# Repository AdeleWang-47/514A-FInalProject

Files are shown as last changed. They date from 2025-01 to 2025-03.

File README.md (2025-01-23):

# 514A-FInalProject
## Section 1
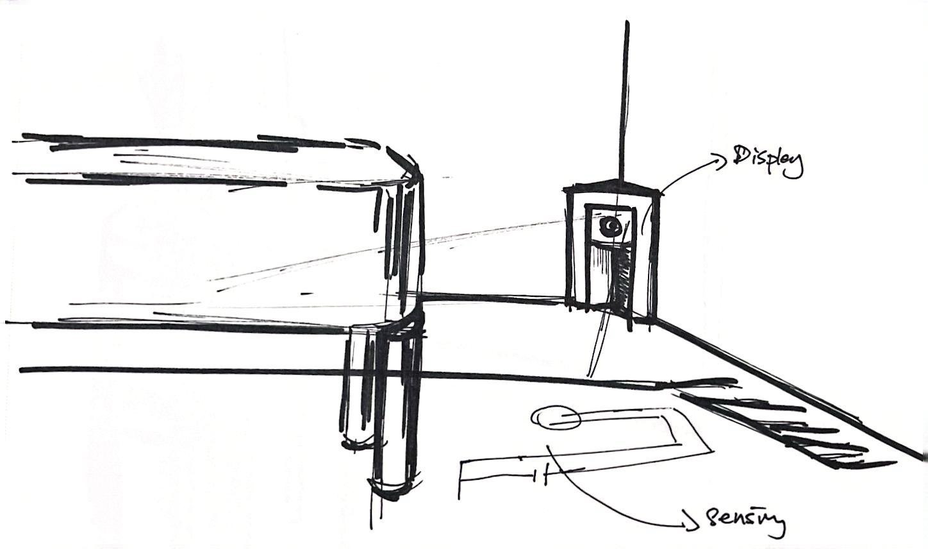
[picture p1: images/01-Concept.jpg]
Concept

A system to provide safe, low-brightness lighting when users get out of bed at night. 
One sensing device shaped like a carpet and one displaying device can be place at the corner of the room to light the path for user.

## Section 2
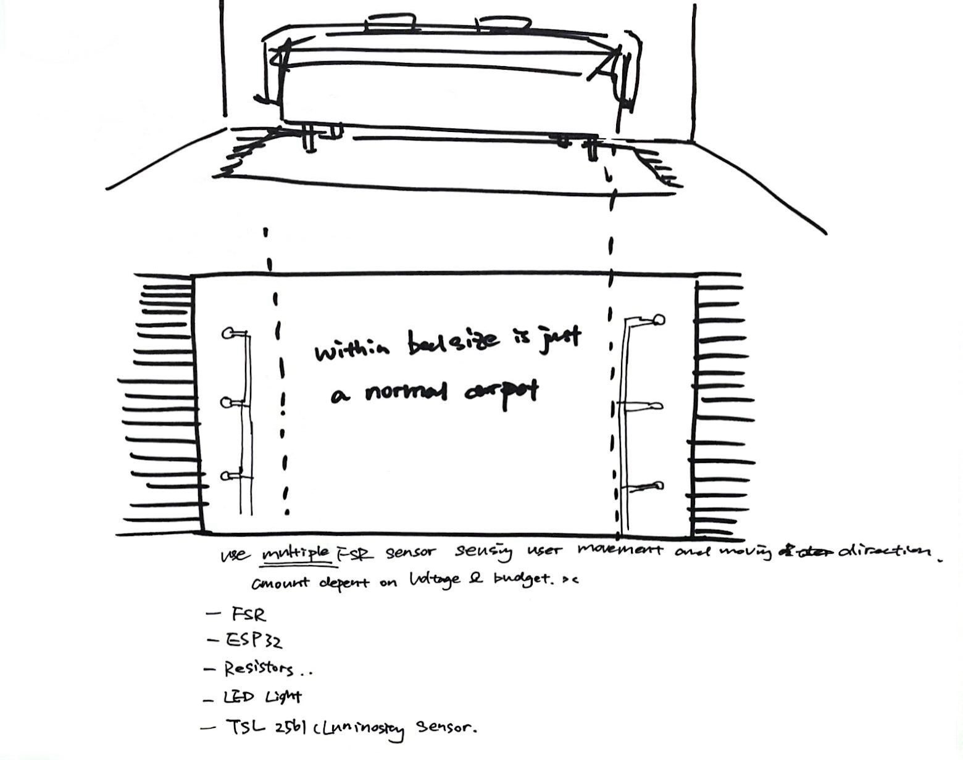
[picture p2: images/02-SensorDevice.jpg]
Sensor

## Section 3
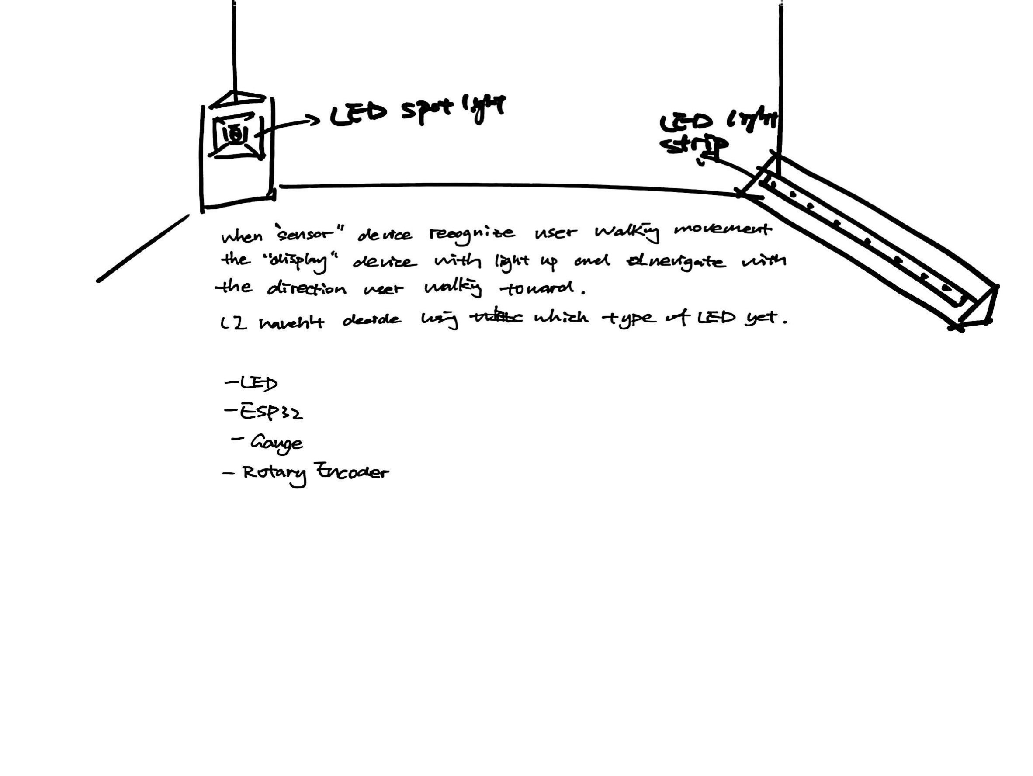
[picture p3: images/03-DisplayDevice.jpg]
Display

## Section 4
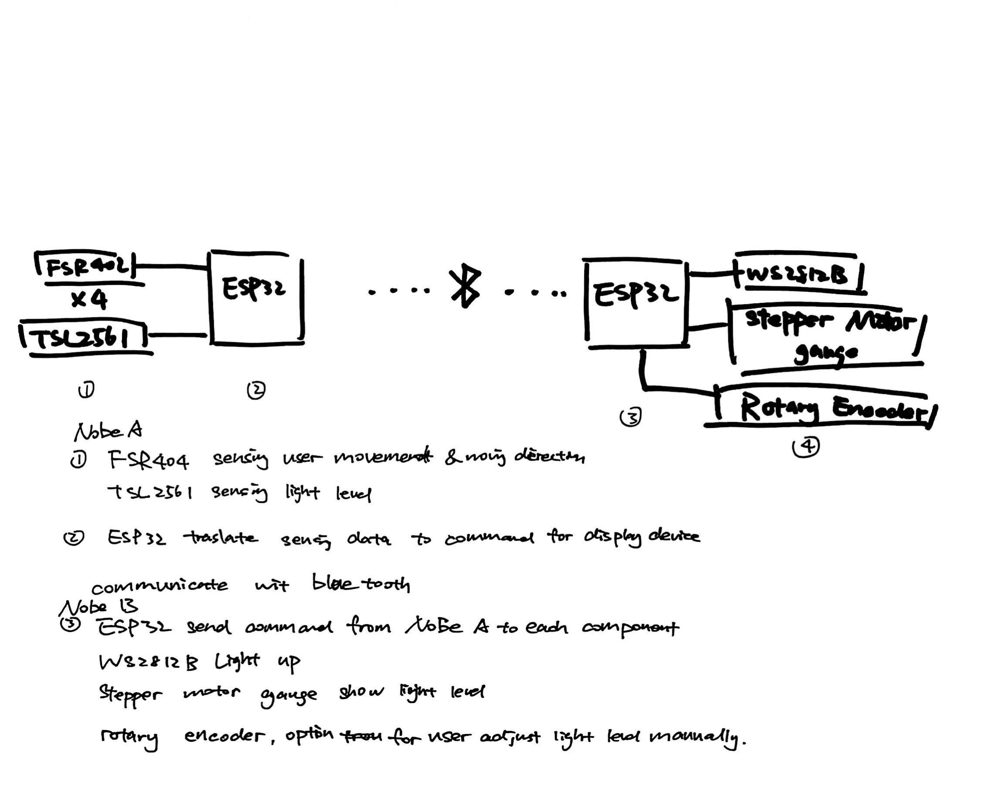
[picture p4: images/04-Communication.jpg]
Communication


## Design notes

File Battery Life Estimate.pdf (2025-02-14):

Battery Life Estimate
TECHIN 514
Adele Wang
13.02.2025

Power Consumption of Each Node

Node A (Sensing Node)

Component | Voltage (V) | Current (mA) | Power (mW)
ESP32-C3 | 3.3V | ~100mA | 330mW
FSR Sensors (x4) | 3.3V | ~4mA each | 13.2mW
Light Sensor (TSL2591) | 3.3V | ~0.4mA | 1.32mW
Total Power for Node A | - | - | ~345mW

Node B (Display & Output Node)

Component | Voltage (V) | Current (mA) | Power (mW)
ESP32-C3 | 3.3V | ~100mA | 330mW
Stepper Motor (X27) | 3.3V | ~150mA | ~500mW
WS2812B LED Strip (1m, 60 LEDs) | 5V (separate power) | ~1200mA max | 6000mW max
Total Power for Node B (excluding LEDs) | - | - | ~830mW

System Usage Model

- Estimate 4 times per night
- Each usage lasts 5 minutes
- Total daily usage: 20 minutes

Battery Selection & Capacity Calculation

Nodes A & B (ESP32 + Sensors + Stepper) - Powered by 18650 Battery

Daily Energy Consumption (20 min/day)

Node | Power (mW) | Daily Usage (min) | Daily Energy (mWh)
Node A (ESP32 + sensors) | ~345mW | 20 | 115mWh
Node B (ESP32 + stepper, excluding LEDs) | ~830mW | 20 | 277mWh
Total Energy (both nodes) | - | - | 392mWh/day

Battery Energy Available (18650 Li-ion 3.7V, 2500mAh)
2500mAh×3.7V=9250mWh

After LDO conversion (~85% efficiency):

9250mWh×0.85=7862.5mWh

Estimated Battery Life

For a 2500mAh 18650 battery:

Node | Battery Life (2500mAh 18650)
Node A (ESP32 + sensors) | ~68.3 days
Node B (ESP32 + stepper) | ~28.4 days

For a 3500mAh 18650 battery:

Node | Battery Life (3500mAh 18650)
Node A (ESP32 + sensors) | ~95.7 days
Node B (ESP32 + stepper) | ~39.8 days

WS2812B LED Strip - Powered by USB Power Bank

- Max Power Consumption: 6000mW (full brightness)
- Estimated Duty Cycle (~30%) → 1800mW average
- Daily Usage: 20 min

1800mW×2060=600mWh/day

For a 10,000mAh USB power bank (5V):

10,000mAh×5V=50,000mWh

Estimated LED Strip Runtime
50,000mWh600mWh≈83 days

Final Battery Life Estimates

System | Power Source | Estimated Runtime Before Recharge
Node A (ESP32 + sensors) | 18650 (3.7V, 2500mAh) | ~68.3 days
Node B (ESP32 + stepper motor) | 18650 (3.7V, 2500mAh) | ~28.4 days
LED Strip (WS2812B, 1m) | USB Power Bank (10,000mAh, 5V) | ~83 days

Reflection

How did you determine your "days of use" metric?

The "days of use" metric is calculated based on the estimated power consumption of each component, the battery capacity, and the expected daily usage.

- Power consumption for each node is determined by summing up the power of all components.
- Daily energy consumption is computed using the estimated duty cycle (4 activations per day, 5 minutes each, totaling 20 minutes/day).
- Battery life is estimated by dividing the available energy of the battery (considering efficiency loss) by the daily energy consumption.

For the LEDs, I estimate their average power consumption at 30% brightness rather than maximum usage to reflect real-world conditions.

What do you think is the optimum size for the battery in your device?

- For Node A (ESP32 + sensors): A 2500mAh 18650 battery can last ~68.3 days, while a 3500mAh battery extends this to ~95.7 days. Since the sensing node consumes relatively low power, a 2500mAh battery is sufficient for at least 2 months of operation.
- For Node B (ESP32 + stepper motor): A 2500mAh battery provides ~28.4 days of operation, which may require recharging monthly. Upgrading to a 3500mAh battery extends this to ~39.8 days, making it a more practical choice.
- For WS2812B LED Strip: A 10,000mAh USB power bank offers ~83 days of operation. A 5,000mAh power bank would still last ~41 days, making it a good tradeoff between cost and battery life.

Thus, my battery setup would be:
- Node A: 2500mAh (or 3500mAh for longer duration)
- Node B: 3500mAh (to reduce frequent recharges)
- LEDs: 5,000mAh or 10,000mAh USB power bank

What hardware/software/cost/effort tradeoffs could you make to improve the user experience?

Tradeoff Type | Improvement | Pros | Cons
Hardware - LED Power | Lower LED brightness (adaptive control) | Extends USB power bank life | Might reduce visibility

Software - Sleep Mode | Enable deep sleep for ESP32 when idle | Reduces power consumption significantly | Requires additional wake-up logic
Software - Sensor Optimization | Lower FSR & light sensor polling frequency | Less frequent wake-ups save power | Might slightly delay response time

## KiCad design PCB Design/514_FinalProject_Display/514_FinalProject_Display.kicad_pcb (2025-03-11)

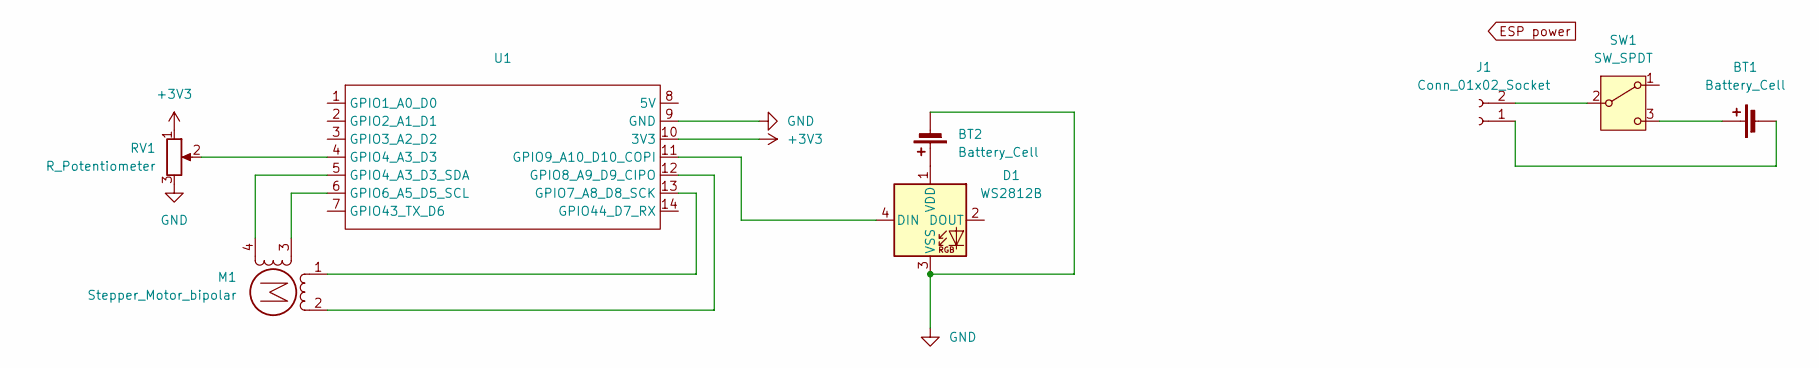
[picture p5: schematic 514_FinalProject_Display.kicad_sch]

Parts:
BT1: Battery_Cell; BatteryHolder_Keystone_1042_1x18650
BT2: Battery_Cell; BarrelJack_Kycon_KLDX-0202-xC_Horizontal
D1: WS2812B; PinHeader_1x04_P2.54mm_Vertical
J1: Conn_01x02_Socket; PinHeader_1x02_P2.54mm_Vertical
M1: Stepper_Motor_bipolar; x27_stepper
RV1: R_Potentiometer; PinHeader_1x03_P2.54mm_Horizontal
SW1: SW_SPDT; PinHeader_1x03_P2.54mm_Vertical
U1: XIAO_ESP32_SENSE

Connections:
+3V3: RV1.1, U1.10 (3V3)
GND: BT2.2 (-), D1.3 (VSS), RV1.3, U1.9 (GND)
unnamed: BT1.1 (+), SW1.3 (C)
unnamed: BT1.2 (-), J1.1
unnamed: BT2.1 (+), D1.1 (VDD)
unnamed: D1.4 (DIN), U1.11 (GPIO9_A10_D10_COPI)
unnamed: J1.2, SW1.2 (B)
unnamed: M1.2 (-), U1.12 (GPIO8_A9_D9_CIPO)
unnamed: RV1.2, U1.4 (GPIO4_A3_D3)
unnamed: M1.4, U1.5 (GPIO4_A3_D3_SDA)
unnamed: M1.3, U1.6 (GPIO6_A5_D5_SCL)
unnamed: M1.1, U1.13 (GPIO7_A8_D8_SCK)

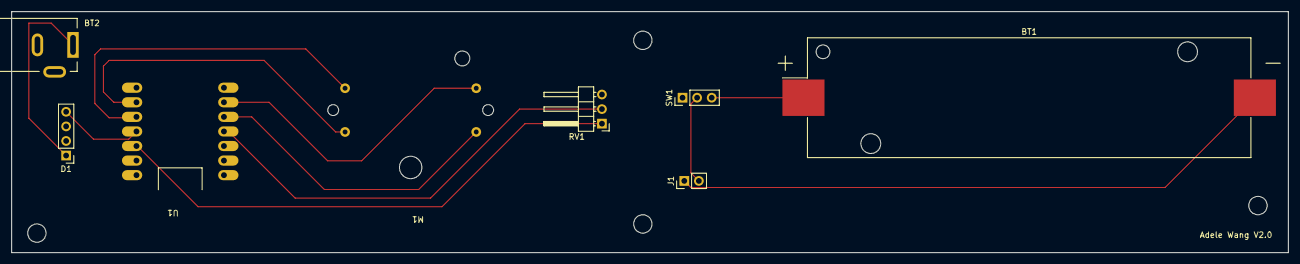
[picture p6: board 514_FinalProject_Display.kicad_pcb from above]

Board: 2 copper layers, 222.5 x 42.0 mm, 8 parts (0 on the bottom side), 12 nets.

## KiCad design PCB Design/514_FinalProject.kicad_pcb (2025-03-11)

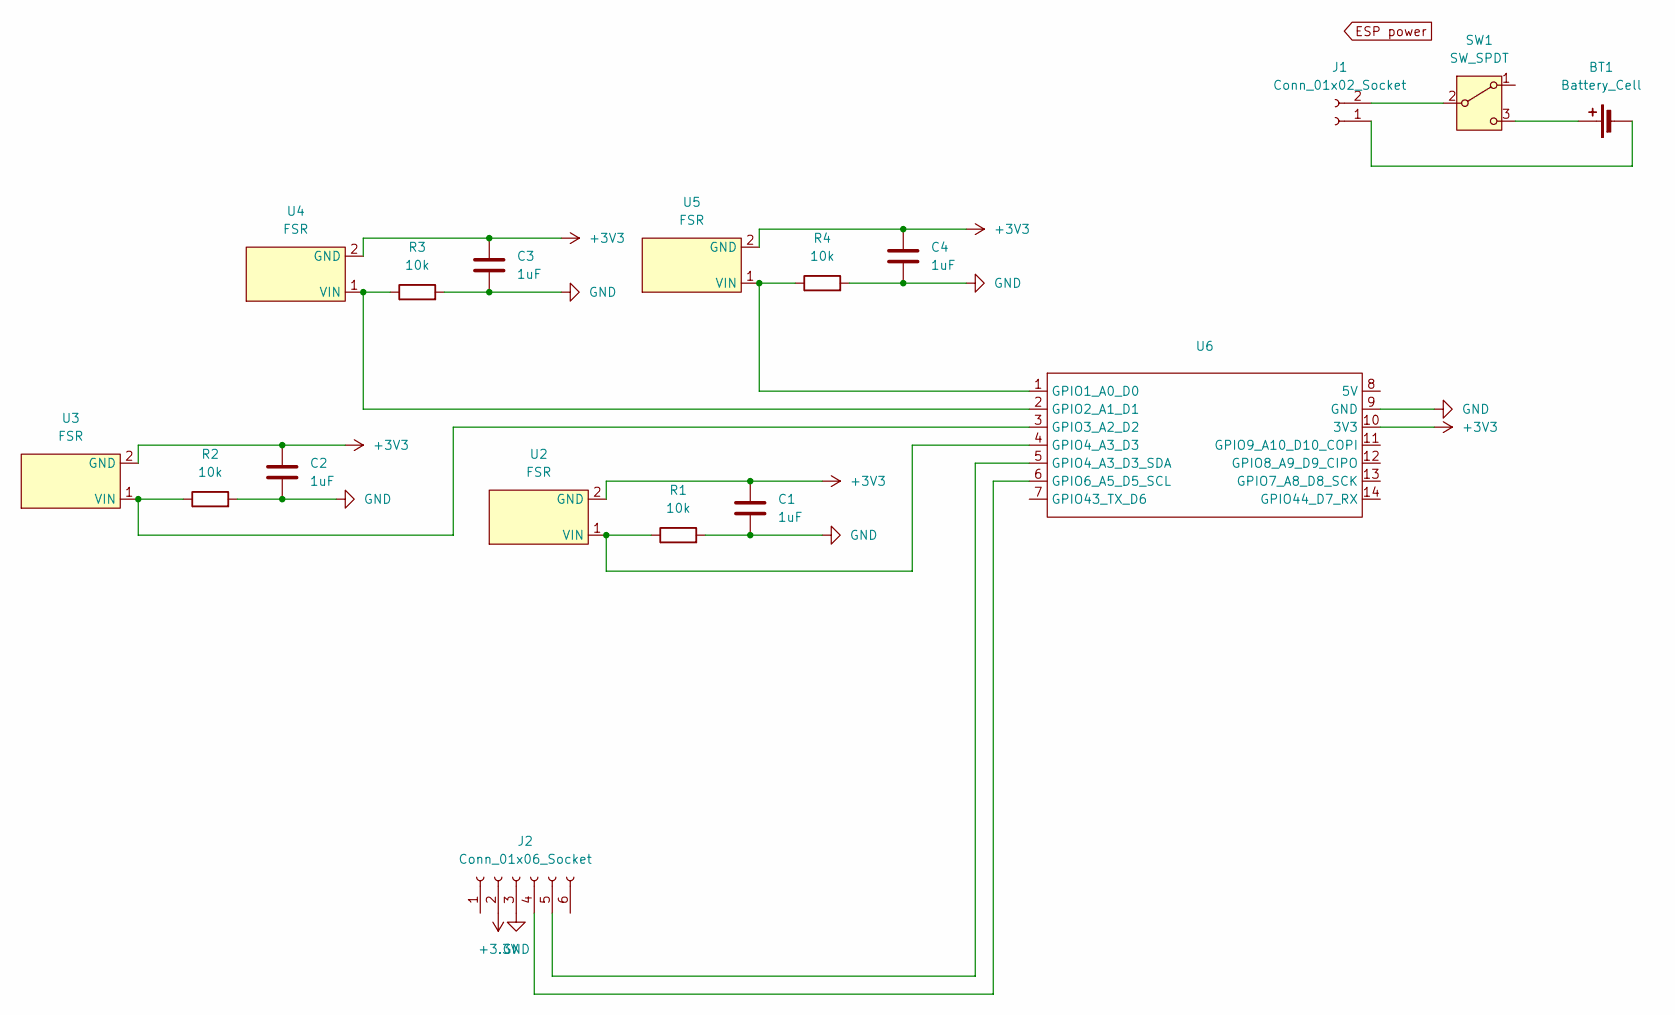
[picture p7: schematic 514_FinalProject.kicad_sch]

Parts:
BT1: Battery_Cell; BatteryHolder_Keystone_1042_1x18650
C1, C2, C3, C4: 1uF; C_0805_2012Metric_Pad1.18x1.45mm_HandSolder
J1: Conn_01x02_Socket; PinHeader_1x02_P2.54mm_Vertical
J2: Conn_01x06_Socket; PinHeader_1x05_P2.54mm_Vertical
R1, R2, R3, R4: 10k; R_0805_2012Metric_Pad1.20x1.40mm_HandSolder
SW1: SW_SPDT; PinHeader_1x03_P2.54mm_Vertical
U2, U3, U4, U5: FSR; PinHeader_1x02_P2.54mm_Vertical
U6: XIAO_ESP32_SENSE

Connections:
+3.3V: J2.2
+3V3: C1.1, C2.1, C3.1, C4.1, U2.2 (GND), U3.2 (GND), U4.2 (GND), U5.2 (GND), U6.10 (3V3)
GND: C1.2, C2.2, C3.2, C4.2, J2.3, R1.2, R2.2, R3.2, R4.2, U6.9 (GND)
unnamed: BT1.1 (+), SW1.3 (C)
unnamed: BT1.2 (-), J1.1
unnamed: J1.2, SW1.2 (B)
unnamed: J2.4, U6.6 (GPIO6_A5_D5_SCL)
unnamed: J2.5, U6.5 (GPIO4_A3_D3_SDA)
unnamed: R1.1, U2.1 (VIN), U6.4 (GPIO4_A3_D3)
unnamed: R2.1, U3.1 (VIN), U6.3 (GPIO3_A2_D2)
unnamed: R3.1, U4.1 (VIN), U6.2 (GPIO2_A1_D1)
unnamed: R4.1, U5.1 (VIN), U6.1 (GPIO1_A0_D0)

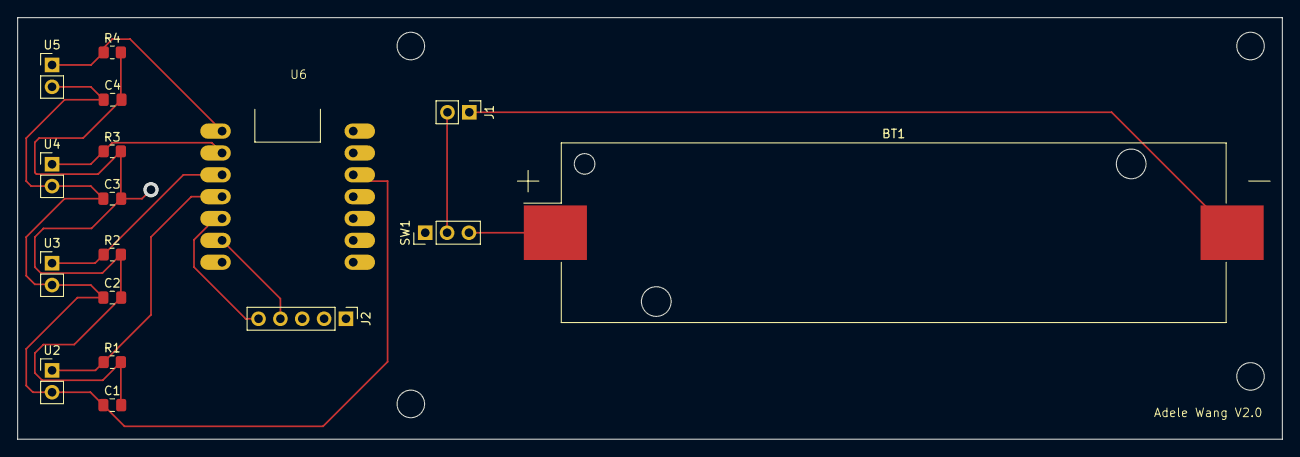
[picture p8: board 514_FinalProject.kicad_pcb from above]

Board: 2 copper layers, 147.0 x 49.0 mm, 17 parts (0 on the bottom side), 11 nets.

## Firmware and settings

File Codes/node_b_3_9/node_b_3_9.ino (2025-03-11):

#include <Arduino.h>
#include <BLEDevice.h>
#include <BLEUtils.h>
#include <BLEScan.h>
#include <BLEClient.h>
#include <BLEAdvertisedDevice.h>
#include <Adafruit_NeoPixel.h>
#include <Stepper.h>

// BLE UUID 定义（与 Server 保持一致）
#define SERVICE_UUID        "4fafc201-1fb5-459e-8fcc-c5c9c331914b"
#define CHARACTERISTIC_UUID "beb5483e-36e1-4688-b7f5-ea07361b26a8"

// LED 灯带定义
#define LED_PIN A10
#define NUM_LEDS 28

// 步进电机引脚定义（按顺序连接到 A4, A5, A9, A8）
#define STEPPER_IN1 A8
#define STEPPER_IN2 A9
#define STEPPER_IN3 A5
#define STEPPER_IN4 A4
#define STEPS_PER_REV 600  // 步进电机一转600步

// POTENTIOMETER 接 A3，用于设置 LED 最大亮度
#define POTENTIOMETER_PIN A3

// 全局 BLE 变量
static BLEAddress *pServerAddress;
bool doConnect = false;
bool connected = false;
BLEClient* pClient = nullptr;
BLERemoteCharacteristic* pRemoteCharacteristic = nullptr;

// 全局变量保存从 Server 接收到的传感器数据（格式："lux,fsr1,fsr2"）
String sensorData = "";

// LED 灯带对象
Adafruit_NeoPixel strip(NUM_LEDS, LED_PIN, NEO_GRB + NEO_KHZ800);
// 步进电机对象
Stepper stepper(STEPS_PER_REV, STEPPER_IN1, STEPPER_IN2, STEPPER_IN3, STEPPER_IN4);

// LED 强制点亮状态和结束时间
bool ledForced = false;
unsigned long ledForcedUntil = 0;

// 通知回调：接收到数据后保存到 sensorData 并打印
void notifyCallback(BLERemoteCharacteristic* pRemoteCharacteristic, uint8_t* pData, size_t length, bool isNotify) {
  sensorData = "";
  for (size_t i = 0; i < length; i++) {
    sensorData += (char)pData[i];
  }
  Serial.print("收到通知: ");
  Serial.println(sensorData);
}

class MyAdvertisedDeviceCallbacks : public BLEAdvertisedDeviceCallbacks {
  void onResult(BLEAdvertisedDevice advertisedDevice) override {
    Serial.println(advertisedDevice.toString().c_str());
    if (advertisedDevice.haveServiceUUID() &&
        advertisedDevice.isAdvertisingService(BLEUUID(SERVICE_UUID))) {
      pServerAddress = new BLEAddress(advertisedDevice.getAddress());
      Serial.print("Found our server: ");
      Serial.println(advertisedDevice.toString().c_str());
      doConnect = true;
      BLEDevice::getScan()->stop();
    }
  }
};

bool connectToServer(BLEAddress pAddress) {
  Serial.print("Forming a connection to ");
  Serial.println(pAddress.toString().c_str());
  
  pClient = BLEDevice::createClient();
  Serial.println(" - Created client");
  
  if (!pClient->connect(pAddress)) {
    Serial.println(" - Failed to connect to server");
    return false;
  }
  Serial.println(" - Connected to server");
  
  BLERemoteService* pRemoteService = pClient->getService(SERVICE_UUID);
  if (pRemoteService == nullptr) {
      Serial.print("Failed to find our service UUID: ");
      Serial.println(SERVICE_UUID);
      pClient->disconnect();
      return false;
  }
  
  pRemoteCharacteristic = pRemoteService->getCharacteristic(CHARACTERISTIC_UUID);
  if (pRemoteCharacteristic == nullptr) {
      Serial.print("Failed to find our characteristic UUID: ");
      Serial.println(CHARACTERISTIC_UUID);
      pClient->disconnect();
      return false;
  }
  
  String value = pRemoteCharacteristic->readValue().c_str();
  Serial.print("Initial characteristic value: ");
  Serial.println(value);
  
  if (pRemoteCharacteristic->canNotify()) {
    pRemoteCharacteristic->registerForNotify(notifyCallback);
    Serial.println("注册通知成功");
  }
  
  return true;
}

void setup() {
  Serial.begin(115200);
  delay(1000);
  Serial.println("启动 Client ...");
  
  // 初始化 LED 灯带和步进电机
  strip.begin();
  strip.show();  // 关闭所有 LED
  stepper.setSpeed(10);
  
  BLEDevice::init("");
  BLEScan* pBLEScan = BLEDevice::getScan();
  pBLEScan->setAdvertisedDeviceCallbacks(new MyAdvertisedDeviceCallbacks());
  pBLEScan->setActiveScan(true);
  Serial.println("开始扫描 BLE 设备...");
  pBLEScan->start(60);  // 扫描 60 秒
}

void loop() {
  if (doConnect) {
    if (connectToServer(*pServerAddress)) {
      Serial.println("We are now connected to the BLE Server.");
      connected = true;
    } else {
      Serial.println("Failed to connect; restarting scan.");
    }
    doConnect = false;
  }
  
  Serial.print("connected = ");
  Serial.println(connected);
  if (pClient != nullptr) {
    Serial.print("pClient->isConnected() = ");
    Serial.println(pClient->isConnected() ? "true" : "false");
  }
  
  // 如果 LED 处于强制点亮状态，实时更新 potentiometer 并调整 LED 亮度
  if (ledForced) {
    // 在强制点亮期间，每次循环更新 LED 亮度
    int potVal = analogRead(POTENTIOMETER_PIN);
    int brightness = map(potVal, 0, 4095, 0, 255);
    Serial.print("Potentiometer raw: ");
    Serial.print(potVal);
    Serial.print(" -> brightness: ");
    Serial.println(brightness);
    if (brightness < 10) brightness = 255; // 默认100%
    
    for (int i = 0; i < NUM_LEDS; i++) {
      strip.setPixelColor(i, strip.Color(brightness, brightness, brightness));
    }
    strip.show();
    
    // 更新步进电机位置
    static int previousStepperPos = 0;
    int targetStepperPos = map(brightness, 0, 255, 0, STEPS_PER_REV);
    int stepsToMove = targetStepperPos - previousStepperPos;
    if (stepsToMove != 0) {
      stepper.step(stepsToMove);
      previousStepperPos = targetStepperPos;
    }
    
    // 检查是否10秒到期
    if (millis() >= ledForcedUntil) {
      // 关闭 LED
      for (int i = 0; i < NUM_LEDS; i++) {
        strip.setPixelColor(i, 0);
      }
      strip.show();
      Serial.println("LED 灯带已自动关闭（10秒到期）");
      ledForced = false;
    }
  }
  // 如果不在强制点亮状态，则处理新的 sensorData
  else if (connected && sensorData.length() > 0) {
    // 解析 sensorData，格式应为 "lux,fsr1,fsr2"
    int firstComma = sensorData.indexOf(",");
    int secondComma = sensorData.indexOf(",", firstComma + 1);
    if (firstComma != -1 && secondComma != -1) {
      int luxValue = sensorData.substring(0, firstComma).toInt();
      int fsr1Value = sensorData.substring(firstComma + 1, secondComma).toInt();
      int fsr2Value = sensorData.substring(secondComma + 1).toInt();
      
      Serial.print("Parsed values: Lux=");
      Serial.print(luxValue);
      Serial.print(", FSR1=");
      Serial.print(fsr1Value);
      Serial.print(", FSR2=");
      Serial.println(fsr2Value);
      
      // 判断条件：如果 lux < 50 且 (fsr1 > 3000 或 fsr2 > 3000)
      if (luxValue < 50 && (fsr1Value > 3000 || fsr2Value > 3000)) {
        Serial.println("条件满足: LED 灯带点亮 10秒");
        
        // 读取 potentiometer设置 LED 最大亮度
        int potVal = analogRead(POTENTIOMETER_PIN);
        int brightness = map(potVal, 0, 4095, 0, 255);
        Serial.print("Potentiometer raw value: ");
        Serial.print(potVal);
        Serial.print(" -> Mapped brightness: ");
        Serial.println(brightness);
        if (brightness < 10) brightness = 255; // 默认 100%
        
        // 点亮 LED 灯带
        for (int i = 0; i < NUM_LEDS; i++) {
          strip.setPixelColor(i, strip.Color(brightness, brightness, brightness));
        }
        strip.show();
        
        // 更新步进电机位置（映射亮度到步进数）
        static int previousStepperPos = 0;
        int targetStepperPos = map(brightness, 0, 255, 0, STEPS_PER_REV);
        int stepsToMove = targetStepperPos - previousStepperPos;
        if (stepsToMove != 0) {
          stepper.step(stepsToMove);
          previousStepperPos = targetStepperPos;
        }
        
        // 设置 LED 强制点亮状态，10秒内实时更新亮度
        ledForcedUntil = millis() + 10000;
        ledForced = true;
      }
    } else {
      Serial.println("解析数据格式出错");
    }
    // 清空 sensorData，避免重复处理
    sensorData = "";
  } else {
    Serial.println("等待 BLE 连接或接收数据...");
  }
  
  delay(1000);
}

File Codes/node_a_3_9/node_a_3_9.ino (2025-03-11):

#include <Arduino.h>
#include <BLEDevice.h>
#include <BLEUtils.h>
#include <BLEServer.h>
#include <Wire.h>
#include <Adafruit_TSL2591.h>

// BLE UUID 定义
#define SERVICE_UUID        "4fafc201-1fb5-459e-8fcc-c5c9c331914b"
#define CHARACTERISTIC_UUID "beb5483e-36e1-4688-b7f5-ea07361b26a8"

// FSR 传感器引脚（模拟输入）
#define FSR_PIN1 A0
#define FSR_PIN2 A1

// TSL2591 I2C 引脚（SDA = D4, SCL = D5）
#define TSL_SDA D4
#define TSL_SCL D5

// 创建 TSL2591 对象
Adafruit_TSL2591 tsl = Adafruit_TSL2591(2591);

BLEServer *pServer = nullptr;
BLECharacteristic *pCharacteristic = nullptr;
bool deviceConnected = false;

// BLE 连接回调
class MyServerCallbacks : public BLEServerCallbacks {
public:
  void onConnect(BLEServer* pServer) override {
    deviceConnected = true;
    Serial.println("Client connected");
  }
  void onDisconnect(BLEServer* pServer) override {
    deviceConnected = false;
    Serial.println("Client disconnected");
    // 断开后重新启动广告
    BLEDevice::startAdvertising();
    Serial.println("Restarting advertising...");
  }
};

void setupTSL2591() {
  Wire.begin(TSL_SDA, TSL_SCL);
  if (!tsl.begin()) {
    Serial.println("TSL2591 not detected! Check wiring.");
    while(1);
  }
  tsl.setGain(TSL2591_GAIN_MED);
  tsl.setTiming(TSL2591_INTEGRATIONTIME_100MS);
}

void setup() {
  Serial.begin(115200);
  delay(1000);
  Serial.println("Starting Server...");

  setupTSL2591();

  // 初始化 BLE
  BLEDevice::init("ESP32C3_SERVER");
  pServer = BLEDevice::createServer();
  pServer->setCallbacks(new MyServerCallbacks());

  BLEService *pService = pServer->createService(SERVICE_UUID);
  pCharacteristic = pService->createCharacteristic(
                      CHARACTERISTIC_UUID,
                      BLECharacteristic::PROPERTY_READ | BLECharacteristic::PROPERTY_NOTIFY
                    );
  pCharacteristic->setValue("0,0,0\n");
  pService->start();

  BLEAdvertising *pAdvertising = BLEDevice::getAdvertising();
  pAdvertising->addServiceUUID(SERVICE_UUID);
  pAdvertising->setScanResponse(true);
  BLEDevice::startAdvertising();

  Serial.println("BLE Server advertising...");
}

void loop() {
  if (deviceConnected) {
    // 获取 TSL2591 数据：32 位原始数据，低16位为 broadband，高16位为 IR
    uint32_t lum = tsl.getFullLuminosity();
    uint16_t broadband = lum & 0xFFFF;
    uint16_t ir = lum >> 16;
    float lux = tsl.calculateLux(broadband, ir);

    // 读取 FSR 数据
    int fsr1 = analogRead(FSR_PIN1);
    int fsr2 = analogRead(FSR_PIN2);

    // 只保留 lux 整数部分，格式：lux,fsr1,fsr2\n
    String sensorData = String((int)lux) + "," + String(fsr1) + "," + String(fsr2) + "\n";
    pCharacteristic->setValue(sensorData.c_str());
    pCharacteristic->notify();
    Serial.println(sensorData);
  }
  else {
    Serial.println("Waiting for BLE connection...");
  }
  
  // 延长发送间隔为 10000 毫秒
  delay(10000);
}

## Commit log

2025-01-29 PCB Design Progress
    [514_FinalProject.kicad_pcb, 514_FinalProject.kicad_sch]
2025-02-14 Battery Life Estimate
    [514_FinalProject-B_Cu.gbr, 514_FinalProject-B_Mask.gbr, 514_FinalProject-B_Paste.gbr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]
